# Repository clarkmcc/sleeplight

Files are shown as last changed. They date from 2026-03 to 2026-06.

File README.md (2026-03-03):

# SleepLight

SleepLight is a BLE-connected bedside light built around an ESP32-C3, with an iOS companion app for color and brightness control.

## Repository layout

- `firmware/` - Rust firmware for the ESP32-C3 (BLE peripheral + LED ring control).
- `ios/` - SwiftUI iOS app that scans, connects, and sends color/brightness updates over BLE.
- `hardware/` - KiCad project, manufacturing outputs, and mechanical assets (`.kicad_*`, Gerbers, STEP/STL).
- `silkscreen.ai` - Illustrator source for silkscreen/artwork.

## Quick start

### 1) Firmware (ESP32-C3)

Prereqs:
- Rust toolchain (stable) with `riscv32imc-unknown-none-elf`
- `probe-rs` installed
- ESP32-C3 board connected via debug probe

From `firmware/`:

```bash
cargo run
```

This uses the configured runner (`probe-rs run --chip esp32c3 ...`) to build and flash.

### 2) iOS app

Prereqs:
- Xcode (current version)
- iOS device or simulator with Bluetooth support (device recommended)

Open and run:
- `ios/SleepLight.xcodeproj`
- Select the `SleepLight` target and run.

The app scans for a BLE peripheral named `SleepLight` and controls RGB + brightness.

## Current BLE contract

- Peripheral name: `SleepLight`
- Light service UUID: `f3e0c001-8b6f-4d2e-a2d0-6b9c3f2a0000`
- State characteristic UUID: `f3e0c002-8b6f-4d2e-a2d0-6b9c3f2a0000`
- Payload format: 4 bytes `[R, G, B, brightness]`

## Licensing

See [licenses](./LICENSES/README.md) for scope mapping.

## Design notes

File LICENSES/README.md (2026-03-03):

# License Scope Map

This repository uses multiple licenses by content type:

- `firmware/` and `ios/`: MIT (`../LICENSE` and `MIT.txt`)
- `hardware/`: CERN-OHL-P-2.0 (`CERN-OHL-P-2.0.txt`)
- Documentation and artwork (including `README.md` and `silkscreen.ai`): CC-BY-4.0 (`CC-BY-4.0.txt`)

For GitHub compatibility, the root `LICENSE` file contains standard MIT text.

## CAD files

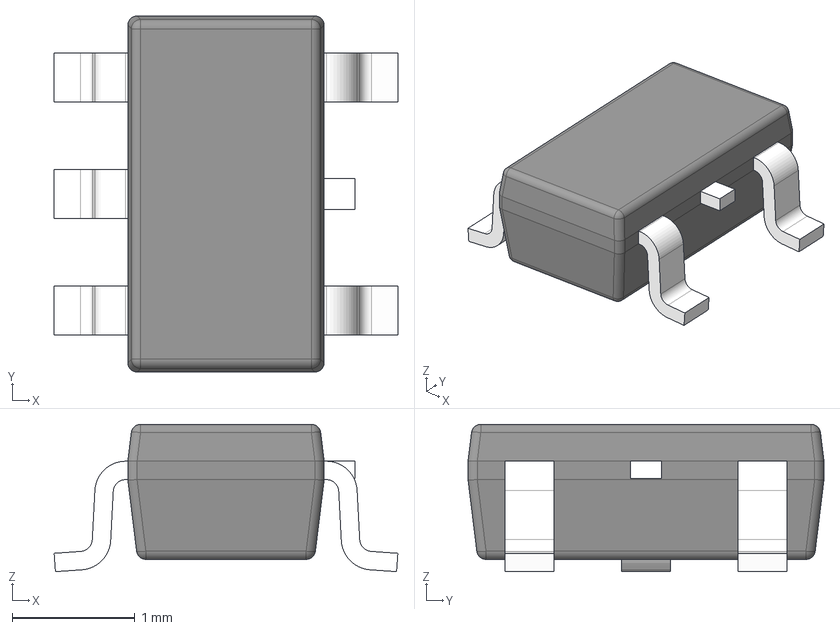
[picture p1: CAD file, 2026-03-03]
hardware/Components/74AHCT1G125DBVRE4/DBV0005A.stp
2.80 x 2.90 x 1.20 mm
BODY-SOT
LEAD-SOT x 5
LEAD-DUMMY

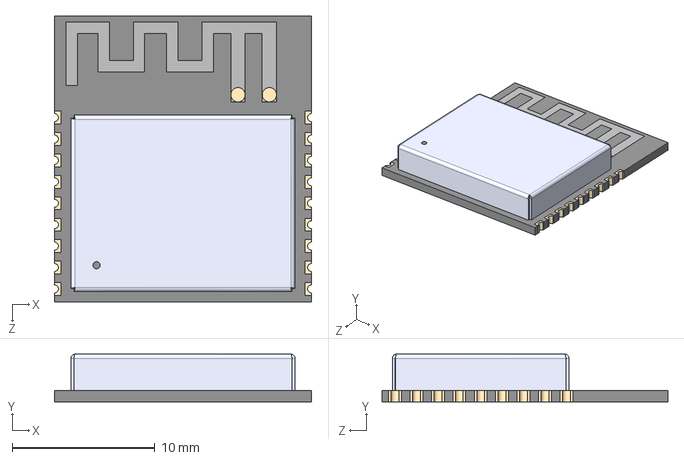
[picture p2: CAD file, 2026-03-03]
hardware/Components/ESP32-C3-WROOM-02-N4/ESP32-C3-WROOM-02-N4.step
18.0 x 3.35 x 20.0 mm

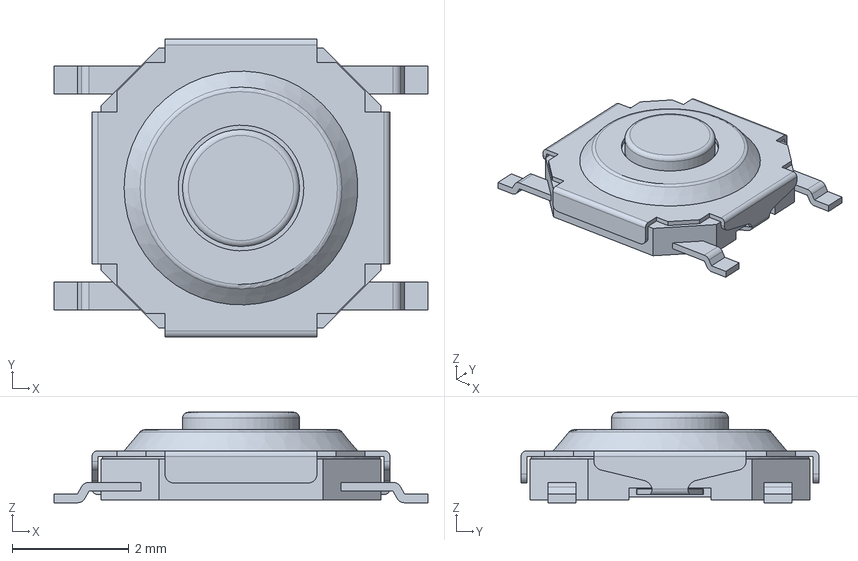
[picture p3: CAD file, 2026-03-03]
hardware/Components/PTS526SM15SMTR2 LFS/PTS526SM15SMTR2LFS.stp
6.40 x 5.10 x 1.55 mm

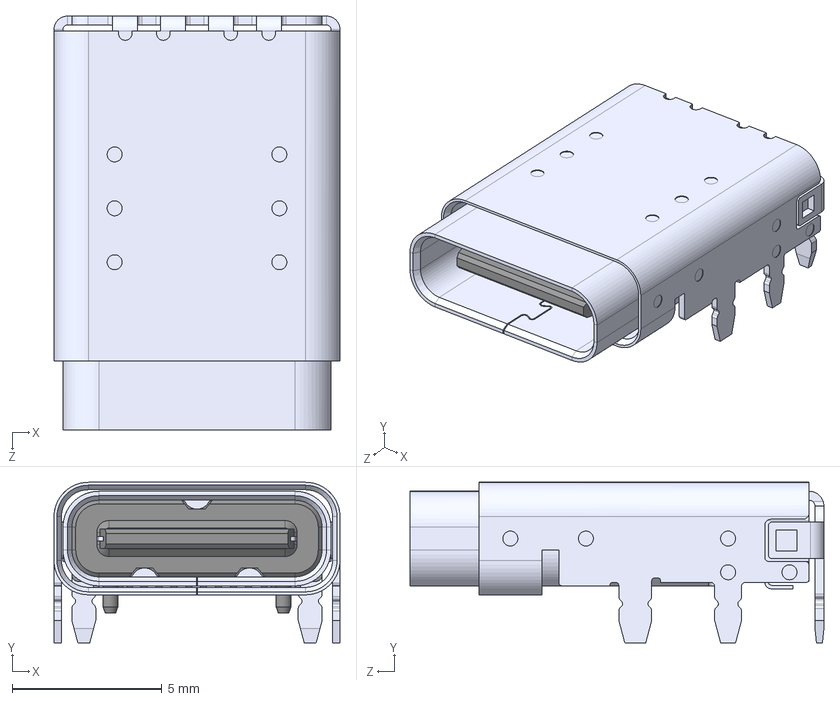
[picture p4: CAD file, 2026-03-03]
hardware/Components/UJ20-C-H-C-1-SMT-TR/UJ20-C-H-C-1-SMT-TR.step
9.55 x 5.36 x 13.8 mm

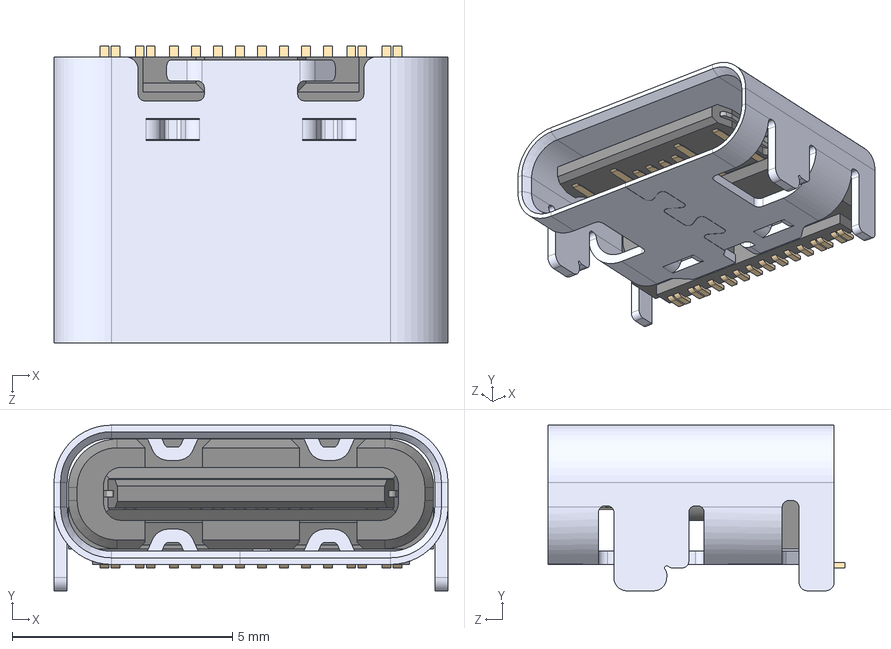
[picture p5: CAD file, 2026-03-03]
hardware/Components/2171790001/2171790001.step
8.94 x 3.76 x 6.75 mm

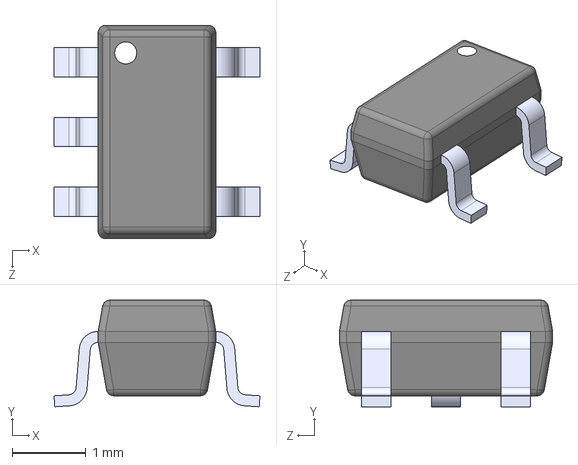
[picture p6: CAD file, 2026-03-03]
hardware/Components/TLV73312PDBVR/TLV73312PDBVR.step
2.80 x 1.45 x 2.90 mm

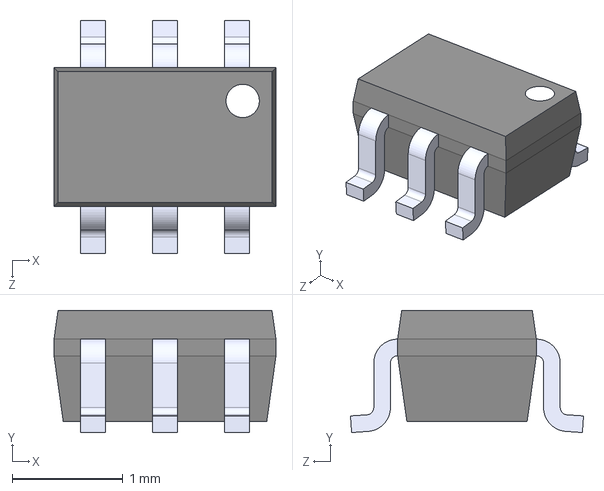
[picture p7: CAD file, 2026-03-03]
hardware/Components/TPS61222DCKT/TPS61222DCKT.step
2.00 x 1.10 x 2.10 mm

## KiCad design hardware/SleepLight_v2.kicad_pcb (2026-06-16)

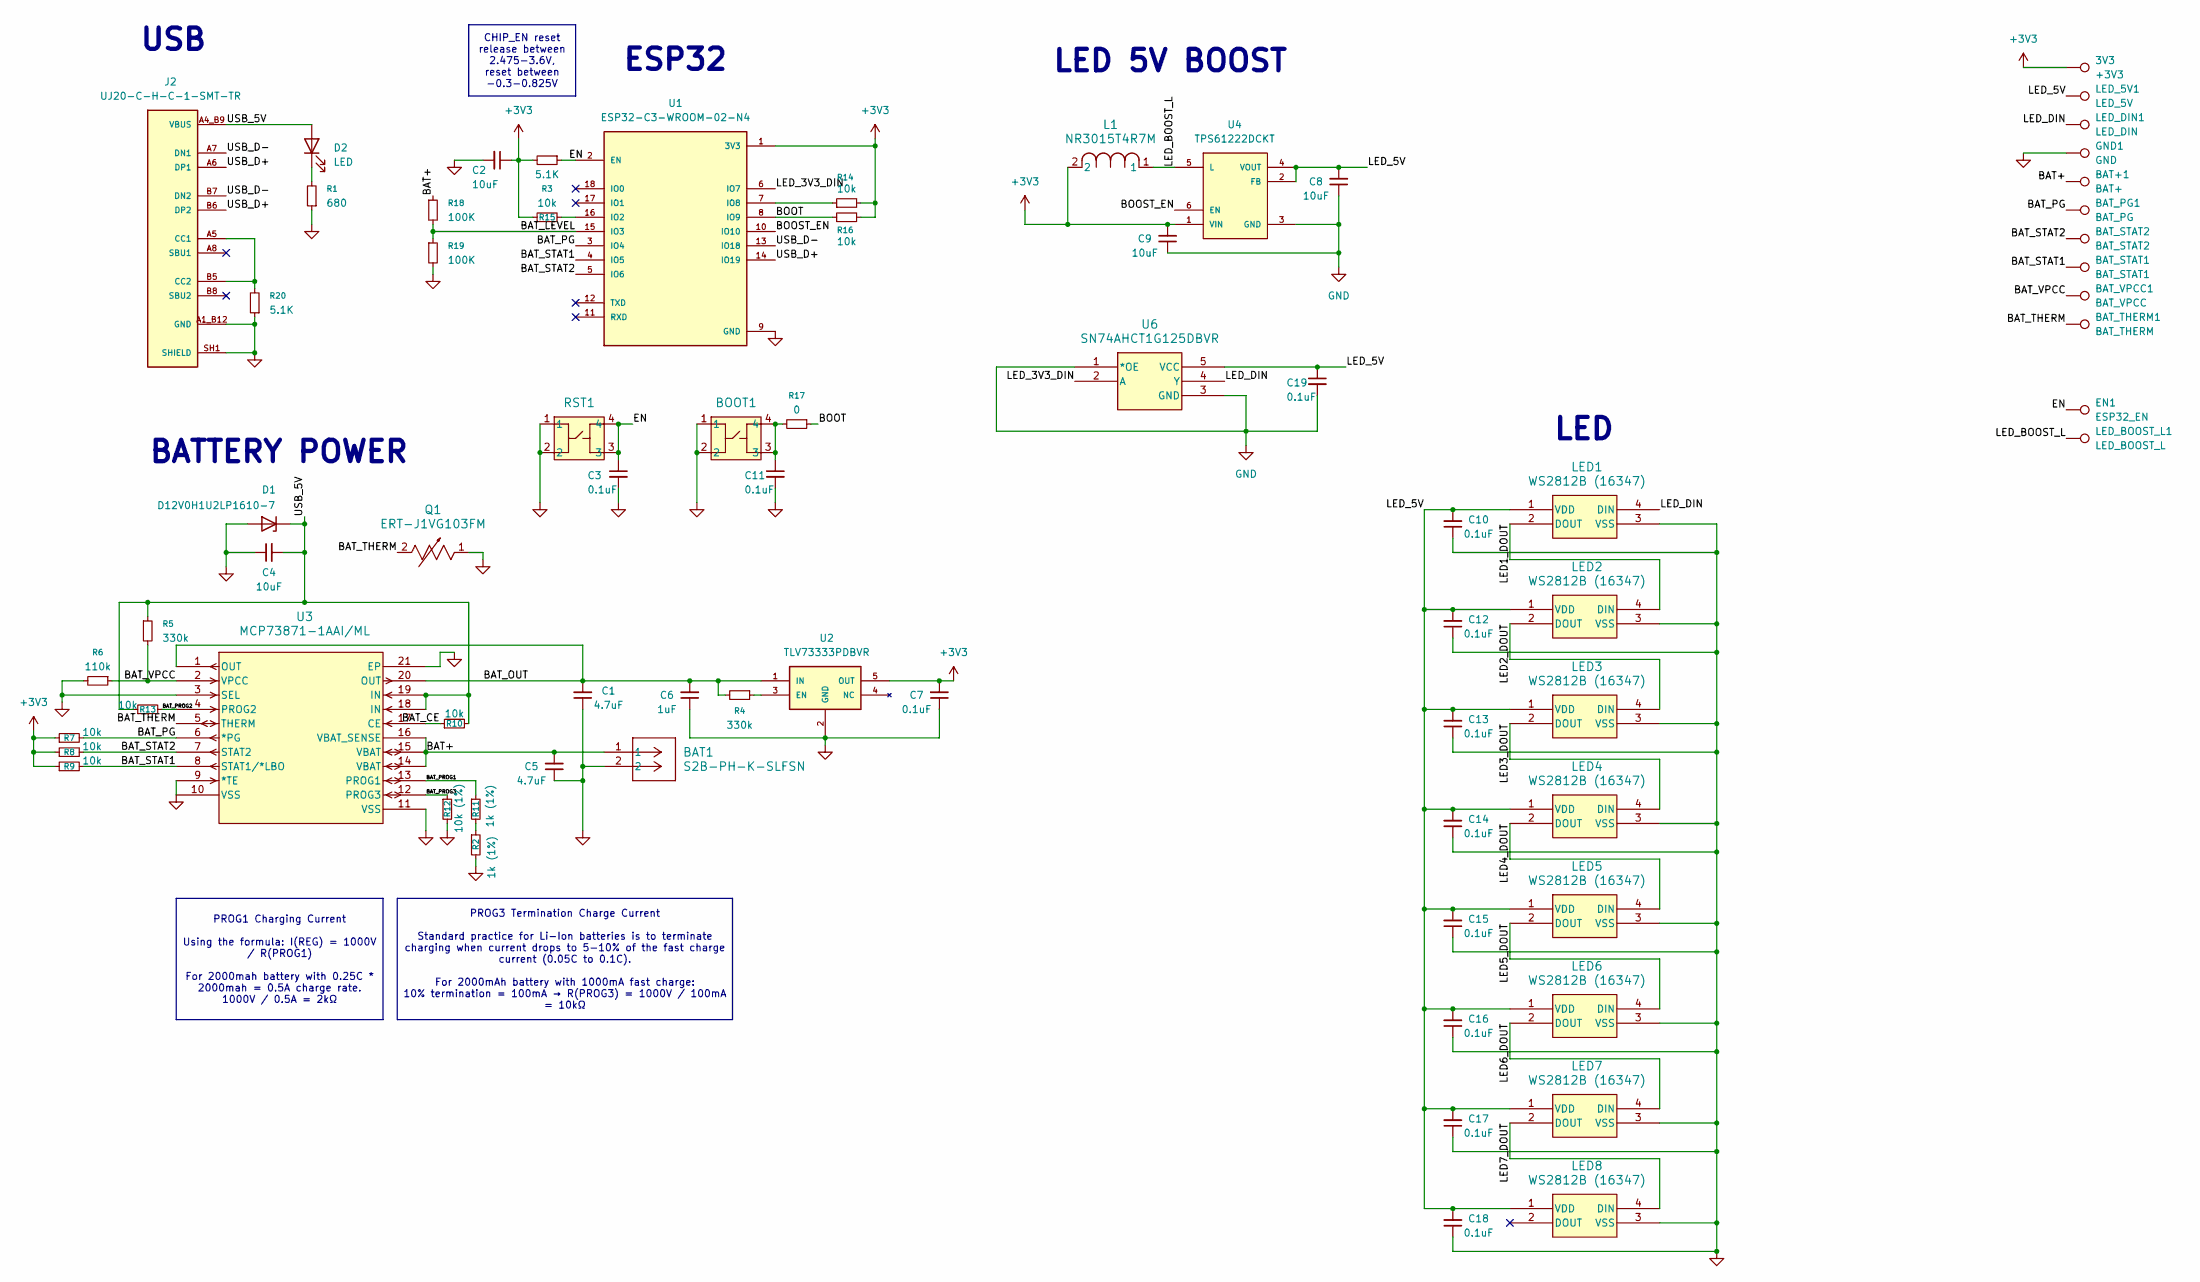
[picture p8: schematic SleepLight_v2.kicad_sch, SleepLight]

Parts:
3V3: +3V3; TestPoint_Pad_1.5x1.5mm
BAT1: S2B-PH-K-SLFSN; CONN_S2B-PH-K-S_JST
BAT+1: BAT+; TestPoint_Pad_1.5x1.5mm
BAT_PG1: BAT_PG; TestPoint_Pad_1.5x1.5mm
BAT_STAT1: BAT_STAT1; TestPoint_Pad_1.5x1.5mm
BAT_STAT2: BAT_STAT2; TestPoint_Pad_1.5x1.5mm
BAT_THERM1: BAT_THERM; TestPoint_Pad_1.5x1.5mm
BAT_VPCC1: BAT_VPCC; TestPoint_Pad_1.5x1.5mm
BOOT1: PTS526 SM15 SMTR2 LFS; SON4_PTS526 SM15 SMTR2 LFS_CNK
C1, C5: 4.7uF; C_0603_1608Metric
C2, C4, C8, C9: 10uF; C_0603_1608Metric
C3, C7, C10, C11, C12, C13, C14, C15, C16, C17, C18, C19: 0.1uF; C_0603_1608Metric
C6: 1uF; C_0603_1608Metric
D1: D12V0H1U2LP1610-7; D_0603_1608Metric; DigiKey_Part_Number D12V0H1U2LP1610-7DICT-ND
D2: LED; LED_0603_1608Metric; DigiKey_Part_Number 160-1478-1-ND
EN1: ESP32_EN; TestPoint_Pad_1.5x1.5mm
GND1: GND; TestPoint_Pad_1.5x1.5mm
J2: UJ20-C-H-C-1-SMT-TR; CUI_UJ20-C-H-C-1-SMT-TR; PARTREV 1.0; DigiKey_Part_Number 2223-UJ20-C-H-C-1-SMT-TRCT-ND
L1: NR3015T4R7M; IND_TAIYO_NR3015_TAY; DigiKey_Part_Number 587-1649-1-ND
LED1, LED2, LED3, LED4, LED5, LED6, LED7, LED8: WS2812B (16347); COM-16347_SPK
LED_5V1: LED_5V; TestPoint_Pad_1.5x1.5mm
LED_BOOST_L1: LED_BOOST_L; TestPoint_Pad_1.5x1.5mm
LED_DIN1: LED_DIN; TestPoint_Pad_1.5x1.5mm
Q1: ERT-J1VG103FM; TRES_ERTJ1_PAN
R1: 680; R_0603_1608Metric
R2, R11: 1k (1%); R_0603_1608Metric; DigiKey_Part_Number RMCF0603FT1K00CT-ND
R3, R20: 5.1K; R_0603_1608Metric
R4, R5: 330k; R_0603_1608Metric
R6: 110k; R_0603_1608Metric
R7, R8, R9, R10, R13, R14, R15, R16: 10k; R_0603_1608Metric
R12: 10k (1%); R_0603_1608Metric; DigiKey_Part_Number 311-10.0KHRCT-ND
R17: 0; R_0603_1608Metric
R18, R19: 100K; R_0603_1608Metric
RST1: PTS526 SM15 SMTR2 LFS; SON4_PTS526 SM15 SMTR2 LFS_CNK; DigiKey_Part_Number CKN12220-1-ND
U1: ESP32-C3-WROOM-02-N4; MODULE_ESP32-C3-WROOM-02-H4; DigiKey_Part_Number 1965-ESP32-C3-WROOM-02-N4CT-ND
U2: TLV73333PDBVR; SOT95P280X145-5N; PARTREV C
U3: MCP73871-1AAI/ML; QFN20_4x4MC_MCH; DigiKey_Part_Number MCP73871-1AAI/ML-ND
U4: TPS61222DCKT; SOT65P210X110-6N
U6: SN74AHCT1G125DBVR; DBV5

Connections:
+3V3: 3V3.1, C2.1, C7.2, C9.2, L1.2, R3.2, R7.1, R8.1, R9.1, R14.2, R15.1, R16.2, U1.1 (3V3), U2.5 (OUT), U4.1 (VIN)
/BAT+: BAT1.1, BAT+1.1, C5.2, R18.1, U3.14 (VBAT), U3.15 (VBAT), U3.16 (VBAT_SENSE)
/BAT_CE: R10.1, U3.17 (CE)
/BAT_LEVEL: R18.2, R19.1, U1.15 (IO3)
/BAT_OUT: C1.2, C6.2, R4.2, U2.1 (IN), U3.1 (OUT), U3.20 (OUT)
/BAT_PG: BAT_PG1.1, R7.2, U1.3 (IO4), U3.6 (*PG)
/BAT_PROG1: R11.1, U3.13 (PROG1)
/BAT_PROG2: R13.2, U3.4 (PROG2)
/BAT_PROG3: R12.1, U3.12 (PROG3)
/BAT_STAT1: BAT_STAT1.1, R9.2, U1.4 (IO5), U3.8 (STAT1/*LBO)
/BAT_STAT2: BAT_STAT2.1, R8.2, U1.5 (IO6), U3.7 (STAT2)
/BAT_THERM: BAT_THERM1.1, Q1.2, U3.5 (THERM)
/BAT_VPCC: BAT_VPCC1.1, R5.2, R6.1, U3.2 (VPCC)
/BOOST_EN: U1.10 (IO10), U4.6 (EN)
/BOOT: R16.1, R17.1, U1.8 (IO9)
/EN: C3.1, EN1.1, R3.1, RST1.3, RST1.4, U1.2 (EN)
/LED1_DOUT: LED1.2 (DOUT), LED2.4 (DIN)
/LED2_DOUT: LED2.2 (DOUT), LED3.4 (DIN)
/LED3_DOUT: LED3.2 (DOUT), LED4.4 (DIN)
/LED4_DOUT: LED4.2 (DOUT), LED5.4 (DIN)
/LED5_DOUT: LED5.2 (DOUT), LED6.4 (DIN)
/LED6_DOUT: LED6.2 (DOUT), LED7.4 (DIN)
/LED7_DOUT: LED7.2 (DOUT), LED8.4 (DIN)
/LED_3V3_DIN: U1.6 (IO7), U6.2 (A)
/LED_5V: C8.2, C10.2, C12.2, C13.2, C14.2, C15.2, C16.2, C17.2, C18.2, C19.1, LED1.1 (VDD), LED2.1 (VDD), LED3.1 (VDD), LED4.1 (VDD), LED5.1 (VDD), LED6.1 (VDD), LED7.1 (VDD), LED8.1 (VDD), LED_5V1.1, U4.2 (FB), U4.4 (VOUT), U6.5 (VCC)
/LED_BOOST_L: L1.1, LED_BOOST_L1.1, U4.5 (L)
/LED_DIN: LED1.4 (DIN), LED_DIN1.1, U6.4 (Y)
/USB_5V: C4.2, D1.1 (K), D2.2 (A), J2.A4_B9 (VBUS), J2.B4_A9 (VBUS), R5.1, R10.2, R13.1, U3.18 (IN), U3.19 (IN)
/USB_D+: J2.A6 (DP1), J2.B6 (DP2), U1.14 (IO19)
/USB_D-: J2.A7 (DN1), J2.B7 (DN2), U1.13 (IO18)
GND: BAT1.2, BOOT1.1, BOOT1.2, C1.1, C2.2, C3.2, C4.1, C5.1, C6.1, C7.1, C8.1, C9.1, C10.1, C11.2, C12.1, C13.1, C14.1, C15.1, C16.1, C17.1, C18.1, C19.2, D1.2 (A), GND1.1, J2.A1_B12 (GND), J2.B1_A12 (GND), J2.SH1 (SHIELD), J2.SH2 (SHIELD), J2.SH3 (SHIELD), J2.SH4 (SHIELD), J2.SH5 (SHIELD), J2.SH6 (SHIELD), LED1.3 (VSS), LED2.3 (VSS), LED3.3 (VSS), LED4.3 (VSS), LED5.3 (VSS), LED6.3 (VSS), LED7.3 (VSS), LED8.3 (VSS), Q1.1, R1.1, R2.2, R6.2, R12.2, R19.2, R20.1, RST1.1, RST1.2, U1.9 (GND), U1.19 (GND), U1.20 (GND), U1.21 (GND), U1.22 (GND), U1.23 (GND), U1.24 (GND), U1.25 (GND), U1.26 (GND), U1.27 (GND), U1.28 (GND), U1.29 (GND), U1.30 (GND), U1.31 (GND), U1.32 (GND), U1.33 (GND), U1.34 (GND), U1.35 (GND), U1.36 (GND), U1.37 (GND), U1.38 (GND), U1.39 (GND), U2.2 (GND), U3.3 (SEL), U3.9 (*TE), U3.10 (VSS), U3.11 (VSS), U3.21 (EP), U4.3 (GND), U6.1 (*OE), U6.3 (GND)
unnamed: BOOT1.3, BOOT1.4, C11.1, R17.2
unnamed: D2.1 (K), R1.2
unnamed: J2.A5 (CC1), J2.B5 (CC2), R20.2
unnamed: R2.1, R11.2
unnamed: R15.2, U1.16 (IO2)
unnamed: R14.1, U1.7 (IO8)
unnamed: R4.1, U2.3 (EN)

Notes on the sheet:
ESP32
LED
USB
LED 5V BOOST
BATTERY POWER
PROG3 Termination Charge Current Standard practice for Li-Ion batteries is to terminate charging when current drops to 5-10% of the fast charge current (0.05C to 0.1C). For 2000mAh battery with 1000mA fast charge: 10% termination = 100mA → R(PROG3) = 1000V / 100mA = 10kΩ
PROG1 Charging Current Using the formula: I(REG) = 1000V / R(PROG1) For 2000mah battery with 0.25C * 2000mah = 0.5A charge rate. 1000V / 0.5A = 2kΩ
CHIP_EN reset release between 2.475-3.6V, reset between -0.3-0.825V

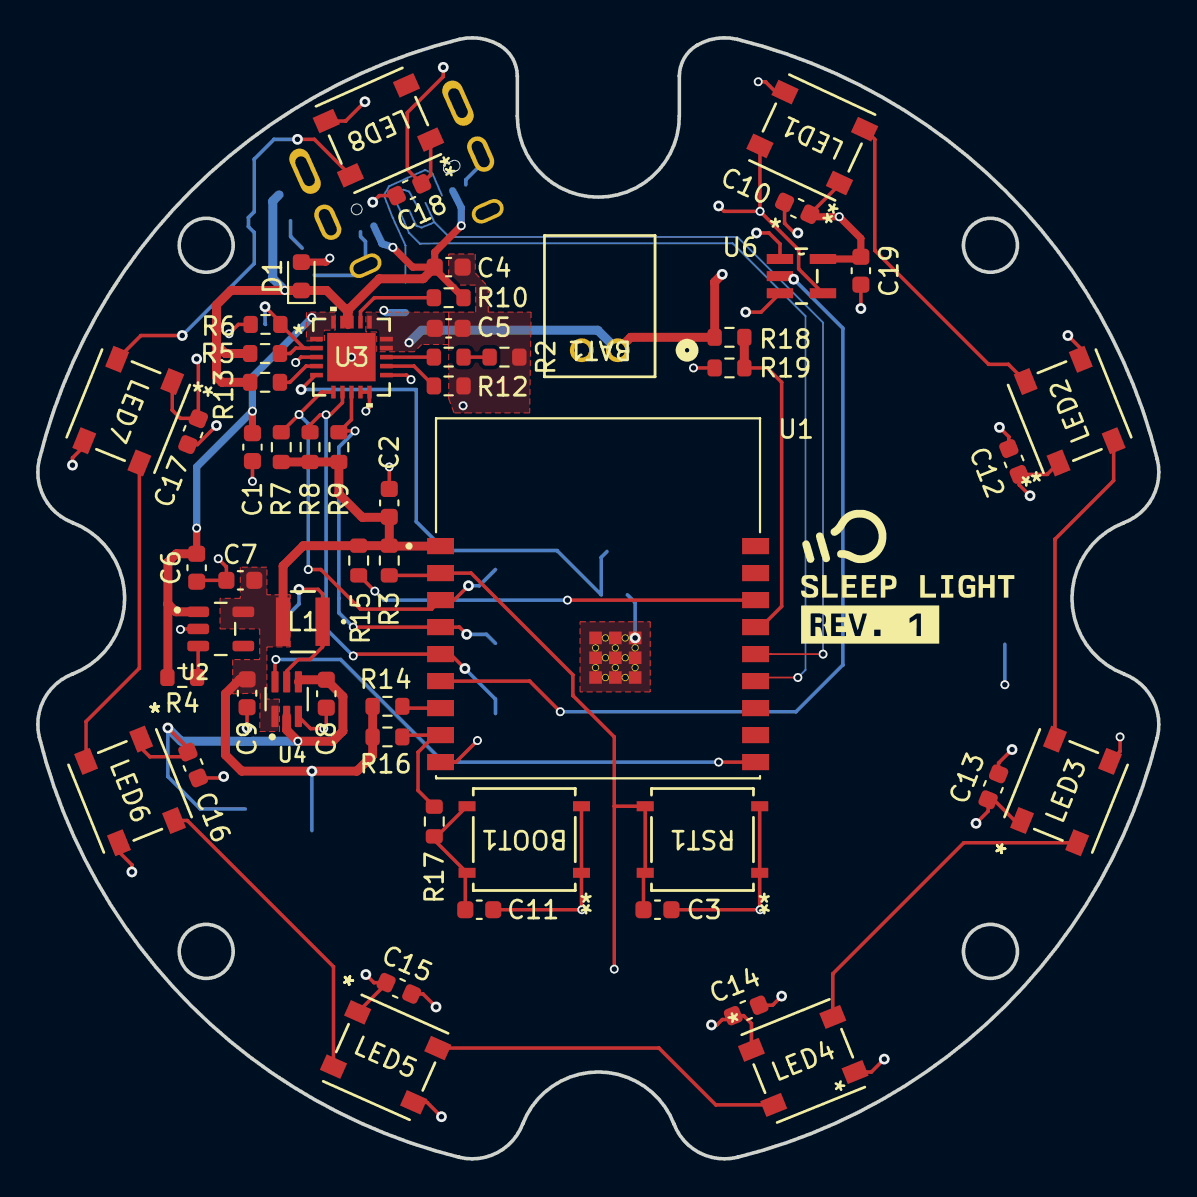
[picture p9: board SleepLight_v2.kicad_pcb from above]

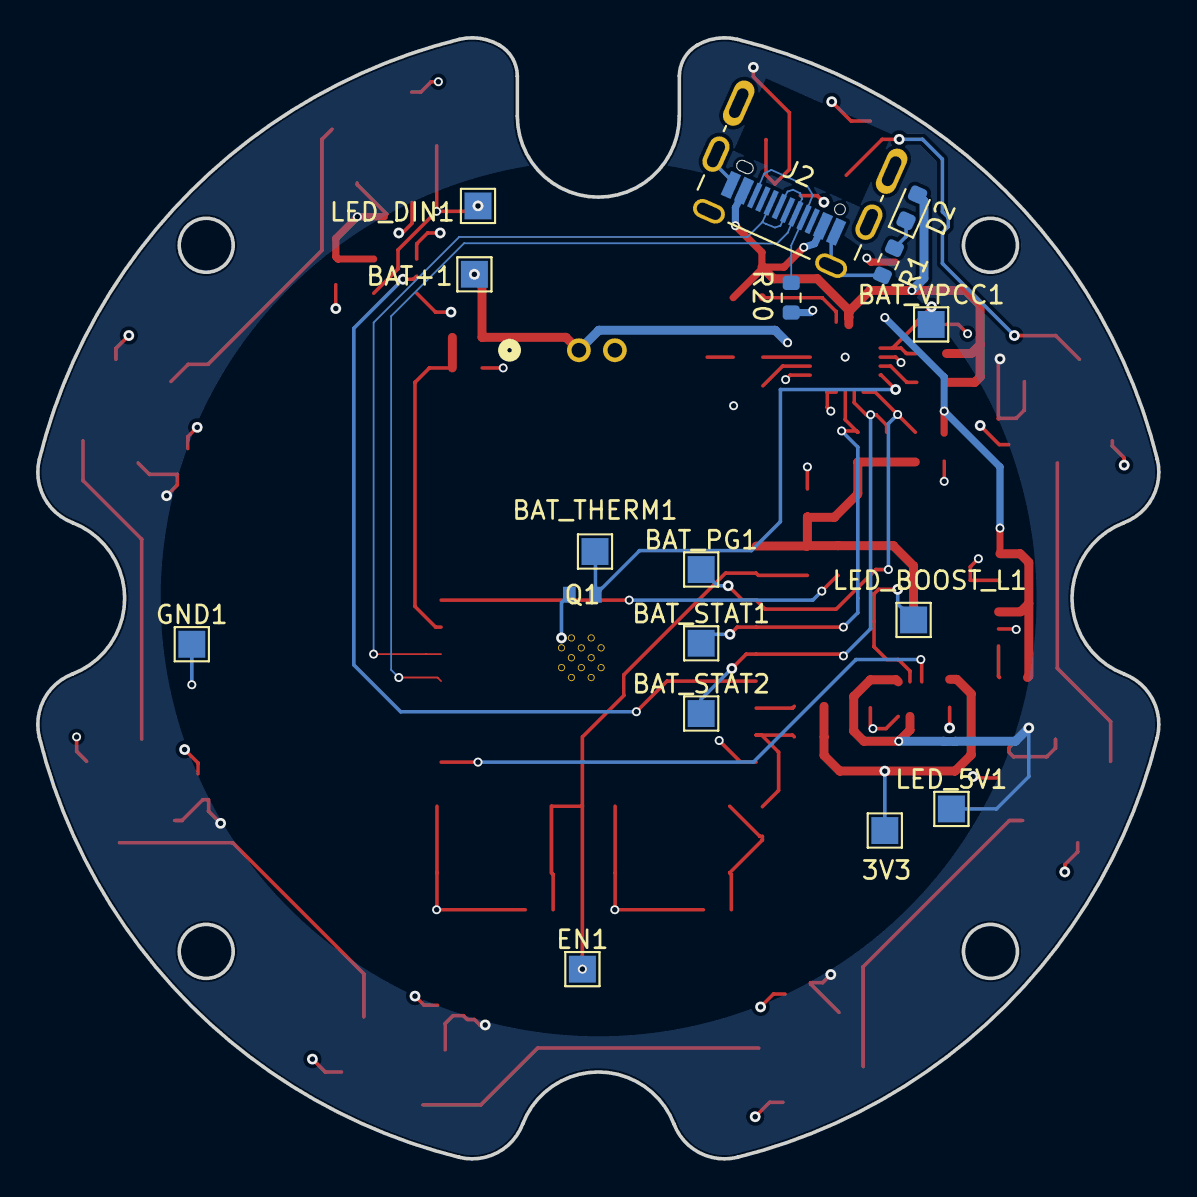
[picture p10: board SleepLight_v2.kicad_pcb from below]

Board: 4 copper layers, 62.3 x 62.3 mm, 72 parts (17 on the bottom side), 38 nets.

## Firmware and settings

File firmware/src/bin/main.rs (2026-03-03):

#![no_std]
#![no_main]
#![deny(
    clippy::mem_forget,
    reason = "mem::forget is generally not safe to do with esp_hal types, especially those \
    holding buffers for the duration of a data transfer."
)]
#![deny(clippy::large_stack_frames)]

use bt_hci::controller::ExternalController;
use embassy_time::{Duration, Timer};
use core::str::FromStr;
use embassy_executor::Spawner;
use embassy_futures::join::join3;
use embassy_sync::blocking_mutex::raw::CriticalSectionRawMutex;
use embassy_sync::channel::Channel;
use esp_hal::analog::adc::{Adc, AdcConfig, Attenuation};
use esp_hal::clock::CpuClock;
use esp_hal::gpio::{Input, InputConfig, Level, Output, OutputConfig};
use esp_hal::rmt::Rmt;
use esp_hal::rng::{Trng};
use esp_hal::time::Rate;
use esp_hal::timer::timg::TimerGroup;
use esp_radio::ble::controller::BleConnector;
use firmware::lightring::{LightRing, LightState};
use rtt_target::rprintln;
use trouble_host::prelude::service::{BATTERY, DEVICE_INFORMATION, GATT};
use trouble_host::prelude::*;

#[panic_handler]
fn panic(info: &core::panic::PanicInfo) -> ! {
    rprintln!("PANIC: {:?}", info);
    loop {}
}

pub enum LightCommand {
    SetState(LightState)
}

extern crate alloc;

const CONNECTIONS_MAX: usize = 1;
const L2CAP_CHANNELS_MAX: usize = 1;

const NAME: &str = "SleepLight";

const BLE_SELF_UUID: u128 = 0xf3e0c0018b6f4d2ea2d06b9c3f2a0000u128;

// This creates a default app-descriptor required by the esp-idf bootloader.
// For more information see: <https://docs.espressif.com/projects/esp-idf/en/stable/esp32/api-reference/system/app_image_format.html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>
esp_bootloader_esp_idf::esp_app_desc!();

#[allow(
    clippy::large_stack_frames,
    reason = "it's not unusual to allocate larger buffers etc. in main"
)]
#[esp_rtos::main]
async fn main(spawner: Spawner) -> ! {
    // generator version: 1.2.0

    rtt_target::rtt_init_print!();

    let config = esp_hal::Config::default().with_cpu_clock(CpuClock::max());
    let peripherals = esp_hal::init(config);

    esp_alloc::heap_allocator!(#[esp_hal::ram(reclaimed)] size: 66320);

    let timg0 = TimerGroup::new(peripherals.TIMG0);
    let sw_interrupt =
        esp_hal::interrupt::software::SoftwareInterruptControl::new(peripherals.SW_INTERRUPT);
    esp_rtos::start(timg0.timer0, sw_interrupt.software_interrupt0);

    rprintln!("Embassy initialized!");

    let radio_init = esp_radio::init().expect("Failed to initialize Wi-Fi/BLE controller");
    // find more examples https://github.com/embassy-rs/trouble/tree/main/examples/esp32
    let transport = BleConnector::new(&radio_init, peripherals.BT, Default::default()).unwrap();
    let ble_controller = ExternalController::<_, 20>::new(transport);
    let mut resources: HostResources<DefaultPacketPool, CONNECTIONS_MAX, L2CAP_CHANNELS_MAX> =
        HostResources::new();
    let _ = spawner;

    let rmt: Rmt<'_, esp_hal::Blocking> = Rmt::new(peripherals.RMT, Rate::from_mhz(80))
        .expect("failed to initialize rmt");

    let ring = LightRing::new(peripherals.GPIO7, rmt.channel1);

    // Pull GPIO10 high to turn on the boost converter
    let _boost = Output::new(peripherals.GPIO10, Level::High, OutputConfig::default());

    let stat1 = Input::new(peripherals.GPIO4, InputConfig::default());
    let stat2 = Input::new(peripherals.GPIO5, InputConfig::default());

    BleServer::run(ble_controller, &ring, &mut resources, &stat1, &stat2).await;
    loop {
        rprintln!("in a loop")
    }
}

#[gatt_server]
pub struct BleServer {
    generic_access: GenericAccess,
    battery_service: BatteryService,
    light_service: LightService,
}

#[gatt_service(uuid = GATT)]
struct GenericAccess {
    #[characteristic(uuid = characteristic::DEVICE_NAME, read, value = HeaplessString::from_str(NAME).unwrap())]
    device_name: HeaplessString<32>,
    #[characteristic(uuid = characteristic::APPEARANCE, read, value = appearance::UNKNOWN)]
    appearance: BluetoothUuid16,
}

#[gatt_service(uuid = BATTERY)]
struct BatteryService {
    #[descriptor(uuid = descriptors::VALID_RANGE, read, value = [0, 100])]
    #[descriptor(uuid = descriptors::MEASUREMENT_DESCRIPTION, value = "Battery Level")]
    #[characteristic(uuid = characteristic::BATTERY_LEVEL, read, write, notify, value = 10)]
    level: u8,
}

const LIGHT_SERVICE: u128 = 0xf3e0c0018b6f4d2ea2d06b9c3f2a0000u128;

#[gatt_service(uuid = LIGHT_SERVICE)]
struct LightService {
    #[descriptor(uuid = descriptors::CHARACTERISTIC_USER_DESCRIPTION, value = "State")]
    #[characteristic(uuid = "f3e0c002-8b6f-4d2e-a2d0-6b9c3f2a0000", read, write, notify, value = 10)]
    state: u32,
}

impl BleServer<'_> {
    pub async fn run<C>(
        controller: C,
        ring: &LightRing<'static>,
        resources: &mut HostResources<DefaultPacketPool, CONNECTIONS_MAX, L2CAP_CHANNELS_MAX>,
        stat1: &Input<'static>,
        stat2: &Input<'static>,
    ) where
        C: Controller,
    {
        let mut buf = [0u8; 6];
        let trng = Trng::try_new().unwrap();
        trng.read(&mut buf);
        let address: Address = Address::random(buf);

        let stack = trouble_host::new(controller, resources).set_random_address(address);
        let host = stack.build();
        let mut peripheral = host.peripheral;

        let mut server = BleServer::new_with_config(GapConfig::Peripheral(PeripheralConfig {
            name: NAME,
            appearance: &appearance::light_source::GENERIC_LIGHT_SOURCE,
        }))
        .expect("create ble server");

        server
            .set(&server.battery_service.level, &70u8)
            .expect("TODO: panic message");

        join3(
            ble_runner(host.runner),
            ble_advertise_loop(&mut peripheral, &mut server, &ring),
            async {
                loop {
                    match (stat1.level(), stat2.level()) {
                        (Level::High, Level::High) => {
                            rprintln!("[bat] shutdown/standby");
                        }
                        (Level::High, Level::Low) => {
                            rprintln!("[bat] charge complete");
                        }
                        (Level::Low, Level::High) => {
                            rprintln!("[bat] preconditioning/fast charge");
                        }
                        (Level::Low, Level::Low) => {
                            rprintln!("[bat] temp/timer fault");
                        }
                        _ => {}
                    }
                    Timer::after(Duration::from_millis(1000)).await;
                }
            }
        )
        .await;
    }
}

async fn ble_runner<C: Controller>(mut runner: Runner<'_, C, DefaultPacketPool>) {
    loop {
        if let Err(e) = runner.run().await {
            panic!("[ble_task] error: {:?}", e);
        }
    }
}

async fn ble_advertise_loop<'ble, C>(
    peripheral: &mut Peripheral<'ble, C, DefaultPacketPool>,
    server: &mut BleServer<'ble>,
    ring: &LightRing<'static>,
) where
    C: Controller,
{
    loop {
        match advertise(peripheral, server).await {
            Ok(conn) => {
                if let Err(err) = ble_handle_conn(server, &conn, &ring).await {
                    rprintln!("[ble_advertise_loop] error handling connection: {:?}", err);
                }
            }
            Err(err) => {
                rprintln!("[ble_advertise_loop] err: {:?}", err);
            }
        }
    }
}

async fn advertise<'values, 'server, C: Controller>(
    peripheral: &mut Peripheral<'values, C, DefaultPacketPool>,
    server: &'server BleServer<'values>,
) -> Result<GattConnection<'values, 'server, DefaultPacketPool>, BleHostError<C::Error>> {
    // Split advertisement data between adv_data and scan_data to fit within 31-byte limits
    let mut advertiser_data = [0; 31];
    let adv_len = AdStructure::encode_slice(
        &[
            AdStructure::Flags(LE_GENERAL_DISCOVERABLE | BR_EDR_NOT_SUPPORTED),
            AdStructure::ServiceUuids16(&[BATTERY.to_le_bytes()]), // Keep only essential service in adv_data
            AdStructure::CompleteLocalName(NAME.as_bytes()),
        ],
        &mut advertiser_data,
    )?;

    // Put additional services in scan response data
    let mut scan_response_data = [0; 31];
    let scan_len = AdStructure::encode_slice(
        &[
            AdStructure::ServiceUuids16(&[DEVICE_INFORMATION.to_le_bytes(), GATT.to_le_bytes()]),
            AdStructure::ServiceUuids128(&[BLE_SELF_UUID.to_le_bytes()]),
        ],
        &mut scan_response_data,
    )?;

    let advertiser = peripheral
        .advertise(
            &Default::default(),
            Advertisement::ConnectableScannableUndirected {
                adv_data: &advertiser_data[..adv_len],
                scan_data: &scan_response_data[..scan_len],
            },
        )
        .await?;
    rprintln!("[adv] advertising");
    let conn = advertiser.accept().await?.with_attribute_server(server)?;
    rprintln!("[adv] connected");
    Ok(conn)
}

async fn ble_handle_conn(server: &BleServer<'_>, conn: &GattConnection<'_, '_, DefaultPacketPool>, ring: &LightRing<'static>) -> Result<(), Error> {
    let reason = loop {
        match conn.next().await {
            GattConnectionEvent::Disconnected { reason } => break reason,
            GattConnectionEvent::Gatt { event } => {
                match &event {
                    GattEvent::Read(_) => {
                    }
                    GattEvent::Write(event) => {
                        rprintln!("[ble_handle_conn] event: handle={},data={:?}", event.handle(), event.data());
                        if event.handle() == server.light_service.state.handle {
                            let value = LightState::from_ble_u32(event.value::<u32>(&server.light_service.state).expect("value"));
                            rprintln!("[ble_handle_conn] setting light state: {:?}", value);
                            ring.set(value);
                        }
                    }
                    _ => {}
                }
                // This step is also performed at drop(), but writing it explicitly is necessary
                // in order to ensure reply is sent.
                match event.accept() {
                    Ok(reply) => reply.send().await,
                    Err(e) => rprintln!("[gatt] Error sending response: {:?}", e),
                }
            }
            GattConnectionEvent::PhyUpdated { .. } => {}
            GattConnectionEvent::ConnectionParamsUpdated { .. } => {}
            GattConnectionEvent::RequestConnectionParams { .. } => {}
            GattConnectionEvent::DataLengthUpdated { .. } => {}
        }
    };
    rprintln!("[gatt] disconnected: {:?}", reason);
    Ok(())
}

struct BatteryStatus {
    stat1: Input<'static>,
    stat2: Input<'static>,
}

impl BatteryStatus {
    fn new(stat1: Input<'static>, stat2: Input<'static>) -> Self {
        BatteryStatus { stat1, stat2 }
    }
}

impl From<BatteryStatus> for u8 {
    fn from(status: BatteryStatus) -> Self {
        let level1 = status.stat1.level();
        let level2 = status.stat2.level();
        match (level1, level2) {
            (Level::High, Level::High) => 1,
            (Level::High, Level::Low) => 2,
            (Level::Low, Level::High) => 3,
            (Level::Low, Level::Low) => 4,
            _ => 0,
        }
    }
}

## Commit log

2026-06-16 fix: ldo en pull-up resistor
    [SleepLight_v2.kicad_pcb, SleepLight_v2.kicad_sch]
2026-06-16 fix: led bypass cap positioning
    [SleepLight_v2.kicad_pcb]
